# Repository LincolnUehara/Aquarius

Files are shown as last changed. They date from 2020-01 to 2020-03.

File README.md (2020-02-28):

# Project Aquarius



<p align="center">
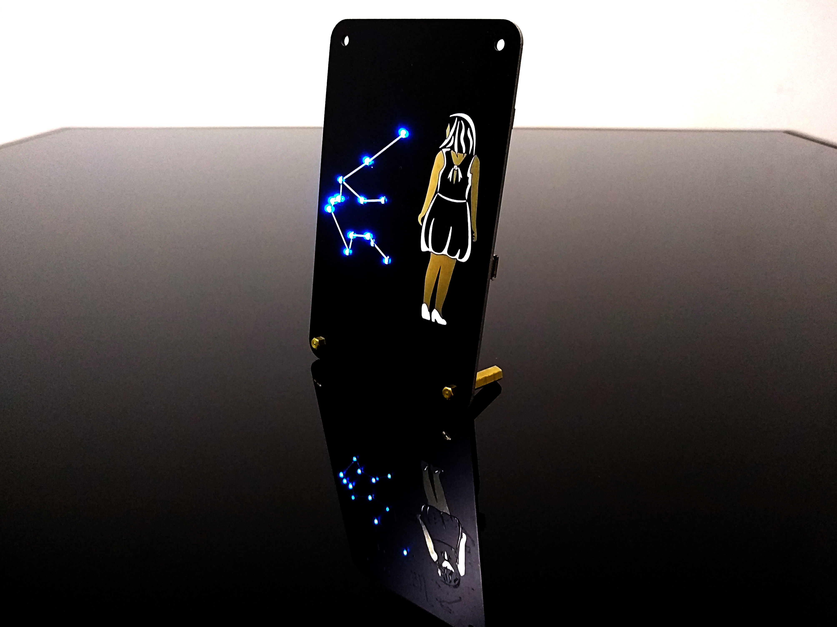
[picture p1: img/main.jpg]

</p>

I was looking for a hardware project to do, and in my research I found about artistical PCBs like [Badgelife](https://www.vice.com/en_us/article/vbne9a/a-history-of-badgelife-def-cons-unlikely-obsession-with-artistic-circuit-boards) and [SAOS](https://hackaday.com/2019/03/20/introducing-the-shitty-add-on-v1-69bis-standard/). Adding to that, since ever I am inspired by a photo that I took from a friend of mine. It looks like she is worry-free, weightless and at peace with herself, but still looking for something, and believing that astral energy wield upon her path.

<p align="center">
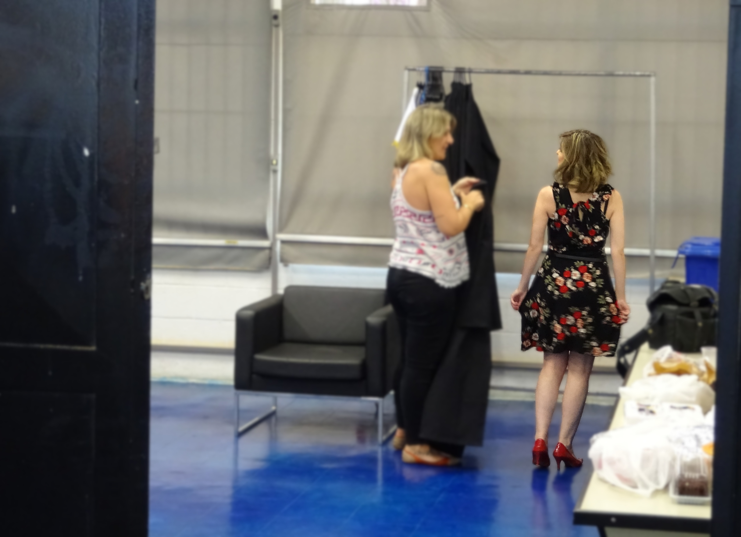
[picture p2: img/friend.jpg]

</p>

Thus, I've decided to make this project happen.

<p align="center">
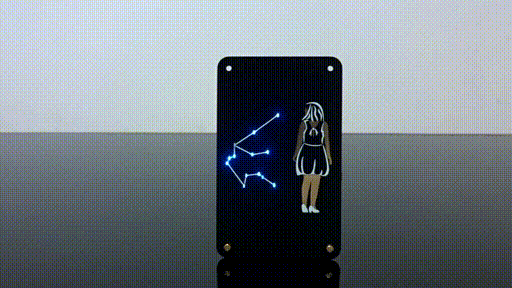
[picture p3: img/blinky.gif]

</p>

There is a _artistical_ promotional video for this project, you can check [here](https://youtu.be/2W8A3zgU_Mk).

### How it works?

Just turn on and the stars will shine! :star2:

* The power supply is from batteries or USB cable accordingly to switch select (where "Choose supply between USB or batteries" is written).

* There is a reset button to just do what it means to, and FTDI pads near to write the firmware into microcontroller.

* There are two trimpot to adjust the intensity and "frequency" of the stars. The stars blink in the way to avoid the predictability, and the control of "frequency" here means to set the average frequency, since each star does not blink every period in the same way.

* There is a USB connection but only for supplying for now. It is not implemented yet any kind of communication with the microcontroller via USB.

<p align="center">
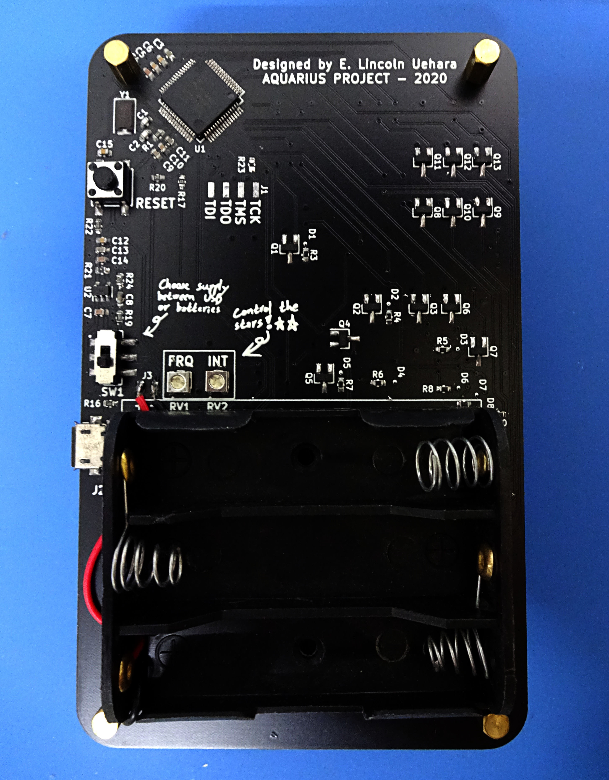
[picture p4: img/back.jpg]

</p>

### Links

* [hackster.io - PCB Portrait "Aquarius"](https://www.hackster.io/lin_hara/pcb-portrait-aquarius-eca035)
* [Kitspace - Aquarius](https://kitspace.org/boards/github.com/lincolnuehara/aquarius/)

### Author

Lincoln Uehara

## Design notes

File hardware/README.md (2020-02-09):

### Setting up Kicad environment

The version used is `5.1.5`.

1. On Symbol Editor:
* Go to _Preferences_ -> _Manage Symbol Libraries..._;
* On _Project Specific Libraries_ tab, add `aquarius.lib` and `ZX62-B-5PA(33).lib`.

2. On Footprint Editor:
* Go to _Preferences_ -> _Manage Footprint Libraries..._;
* On _Project Specific Libraries_ tab add `aquarius.pretty`, `TPS79733DCKT.mod`, `JS202011SCQN.mod` and `PVG3A205C01R00.mod`.

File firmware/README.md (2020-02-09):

### Setting up Eclipse IDE environment

* Go to _Project_ -> _Properties_;
* Go to _C/C++ Build_ -> _Environment_ -> _Variables_
* Just set the _PATH_ variable pointing to the ARM GCC compiler. For example: `${HOME}/opt/${GCC_VERSION}/bin:...`

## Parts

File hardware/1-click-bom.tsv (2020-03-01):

References | Qty | Description | Manufacturer | MPN | Digikey | Mouser | RS | Newark | Farnell
C1, C2 | 2 | C 10pF Unpolarized capacitor 0603 1608Metric | KEMET | C0603C100K4GACTU | C0603C100K4GACTU-ND | 80C0603C100K4GACTU |  |  | 2941182
C3 | 1 | C 2.2uF Unpolarized capacitor 0603 1608Metric | Taiyo Yuden | LMK107BJ225KK-T | 587-6290-6-ND | 963LMK107BJ225KKT
C4, C7, C14 | 3 | C 1.0uF Unpolarized capacitor 0603 1608Metric | TDK | CGA3E1X8L1C105K080AC | 445-175260-1-ND | 810CGA3E1X8L105K080
C6, C5, C10, C12, C15 | 5 | C 0.1uF Unpolarized capacitor 0603 1608Metric | KEMET | C0603X104K5RAC3316 | 399-C0603X104K5RAC3316CT-ND | 80C0603X104K5R3316 | 1882158
C8, C9, C11, C13 | 4 | C 0.01uF Unpolarized capacitor 0603 1608Metric | KEMET | C0603C103K4HACTU |  | 80C0603C103K4HACTU
D1, D2, D3, D4, D5, D11, D12, D13, D6, D7, D8, D9, D10 | 13 | LED Blue 0603 1608Metric | Dialight | 599-0091-007F | 350-4352-1-ND | 6455990091007F
J2 | 1 | USB Connectors MICRO B | Hirose | ZX62-B-5PA(33) | H125270DKR-ND | 798ZX62B5PA33 | 1362267 |  | 2554978
Q1, Q2, Q3, Q4, Q5, Q11, Q12, Q13, Q6, Q7, Q8, Q9, Q10 | 13 | Bipolar Transistors - Pre-Biased NPN SOT-23 | Rohm | DTC114ECAHZGT116 | DTC114ECAHZGT116DKR-ND | 755DTC114ECAHZGT116 |  |  | 2764559
R1, R20, R19, R16, R17 | 5 | R 0 Resistor 0603 1608Metric | Vishay | CRCW06030000Z0EBC | 541-4013-6-ND | 71CRCW06030000Z0EBC
R3, R4, R5, R6, R7, R13, R14, R15, R8, R9, R10, R11, R12 | 13 | R R100 Resistor 0603 1608Metric | KOA Speer | RN73R1JTTD1000F50 | 2019-RN73R1JTTD1000F50TR-ND | 660RN73R1JTD1000F50
R21 | 1 | R 51k Resistor 0603 1608Metric | Rohm | KTR03EZPF5102 | RHM51KAYCT-ND | 755KTR03EZPF5102 |  |  | 2919261
R22 | 1 | R 10k Resistor 0603 1608Metric | Vishay | CRCW060310K0FKEAC | 541-5136-6-ND | 71CRCW060310K0FKEAC
R23 | 1 | R 100k Resistor 0603 1608Metric | Panasonic | ERJ-PA3F1003V | P100KBYDKR-ND | 667ERJPA3F1003V | 8626708 |  | 2335832
R24 | 1 | R 30k Resistor 0603 1608Metric | Vishay | RCS060330K0FKEA | 541-10453-1-ND | 71RCS060330K0FKEA |  |  | 3235100
RV1, RV2 | 2 | SMD Trimmer Resistors 10Kohms | Bourns | PVG3A103C01R00 | 490-2644-2-ND | 81PVG3A103C01R00 | 1814466 |  | 2709480
SW1 | 1 | Slide Switches Slide Switches DPDT | C&K Components | JS202011SCQN | 401-2002-1-ND | 611JS202011SCQN | 1546137 |  | 2320019
SW2 | 1 | Tactile Switch SPST GEN PURPOSE | Omron | B3S-1000 | SW415-ND | 653B3S1000 | 183701 |  | 177807
U1 | 1 | MCU ARM Microcontrollers - Tiva C Series | Texas Instruments | TM4C123GH6PMI | 296-35848-ND | 595TM4C123GH6PMI |  |  | 3008366
U2 | 1 | LDO Voltage Regulators Cap-Free NMOS 400mA | Texas Instruments | TPS73633DBVR | 296-27064-6-ND | 595TPS73633DBVR |  |  | 3007880
Y1 | 1 | Crystal 16MHz SMD | Abracon | ABM3-16.000MHZ-B2-T | 535-9103-1-ND | 815ABM316B2T |  |  | 1611806

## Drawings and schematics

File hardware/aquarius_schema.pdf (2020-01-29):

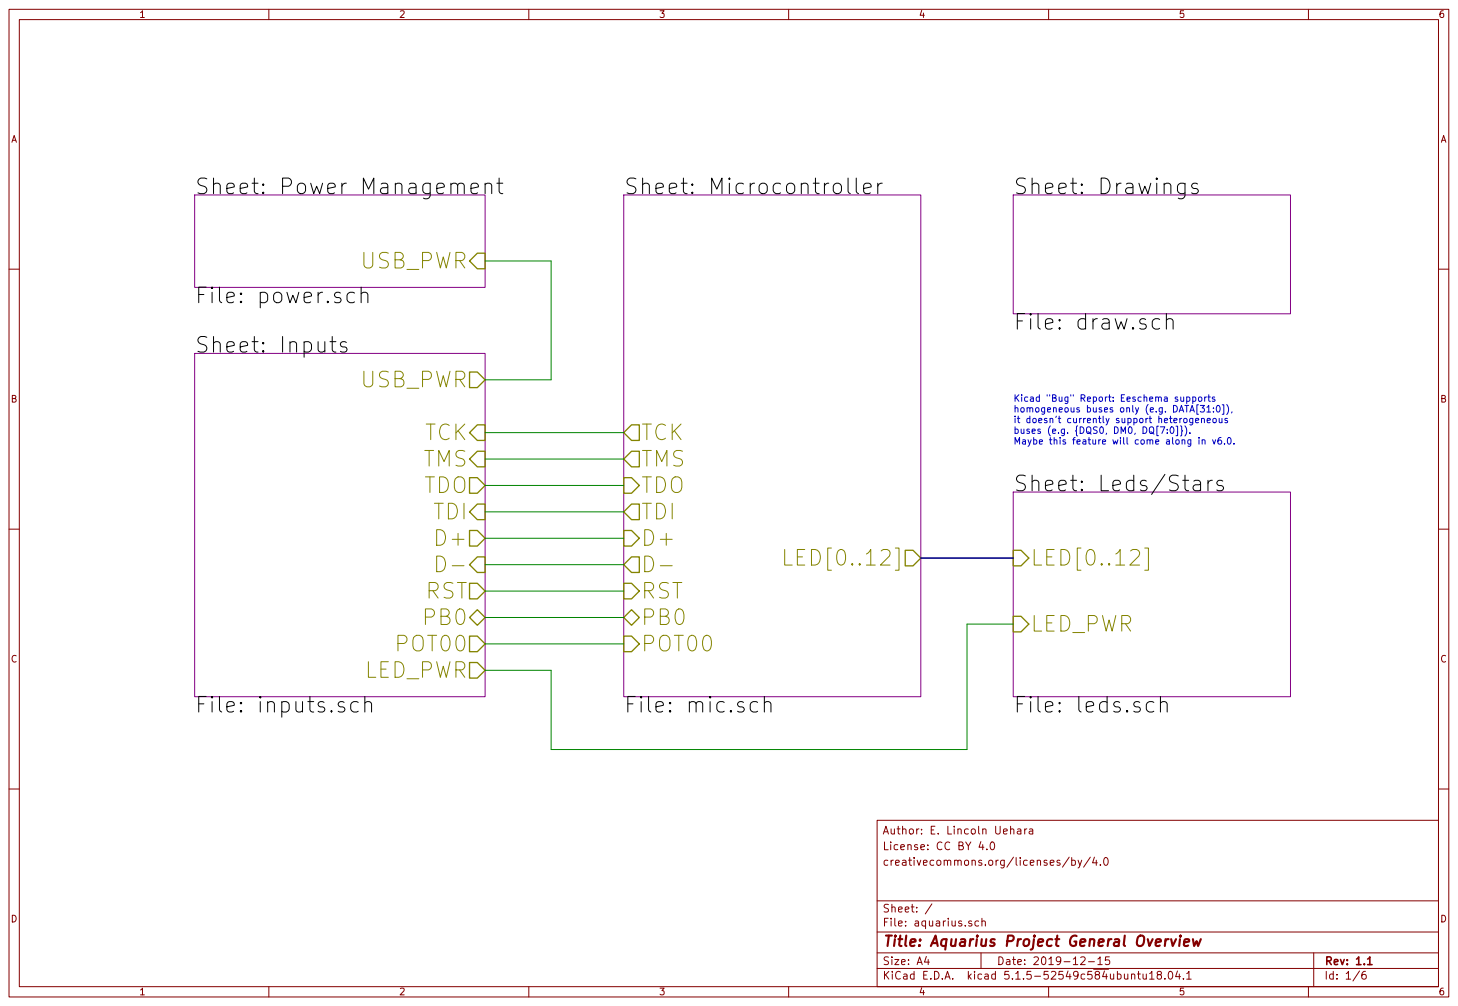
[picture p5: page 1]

Kicad "Bug" Report: Eeschema supports
homogeneous buses only (e.g. DATA[31:0]),
it doesnt currently support heterogeneous
buses (e.g. {DQS0, DM0, DQ[7:0]}).
Maybe this feature will come along in v6.0.

License: CC BY 4.0 Author: E. Lincoln Uehara Sheet: Leds/Stars

File: aquarius.sch Sheet: / creativecommons.org/licenses/by/4.0

Id: 1/6 Title: Aquarius Project General Overview

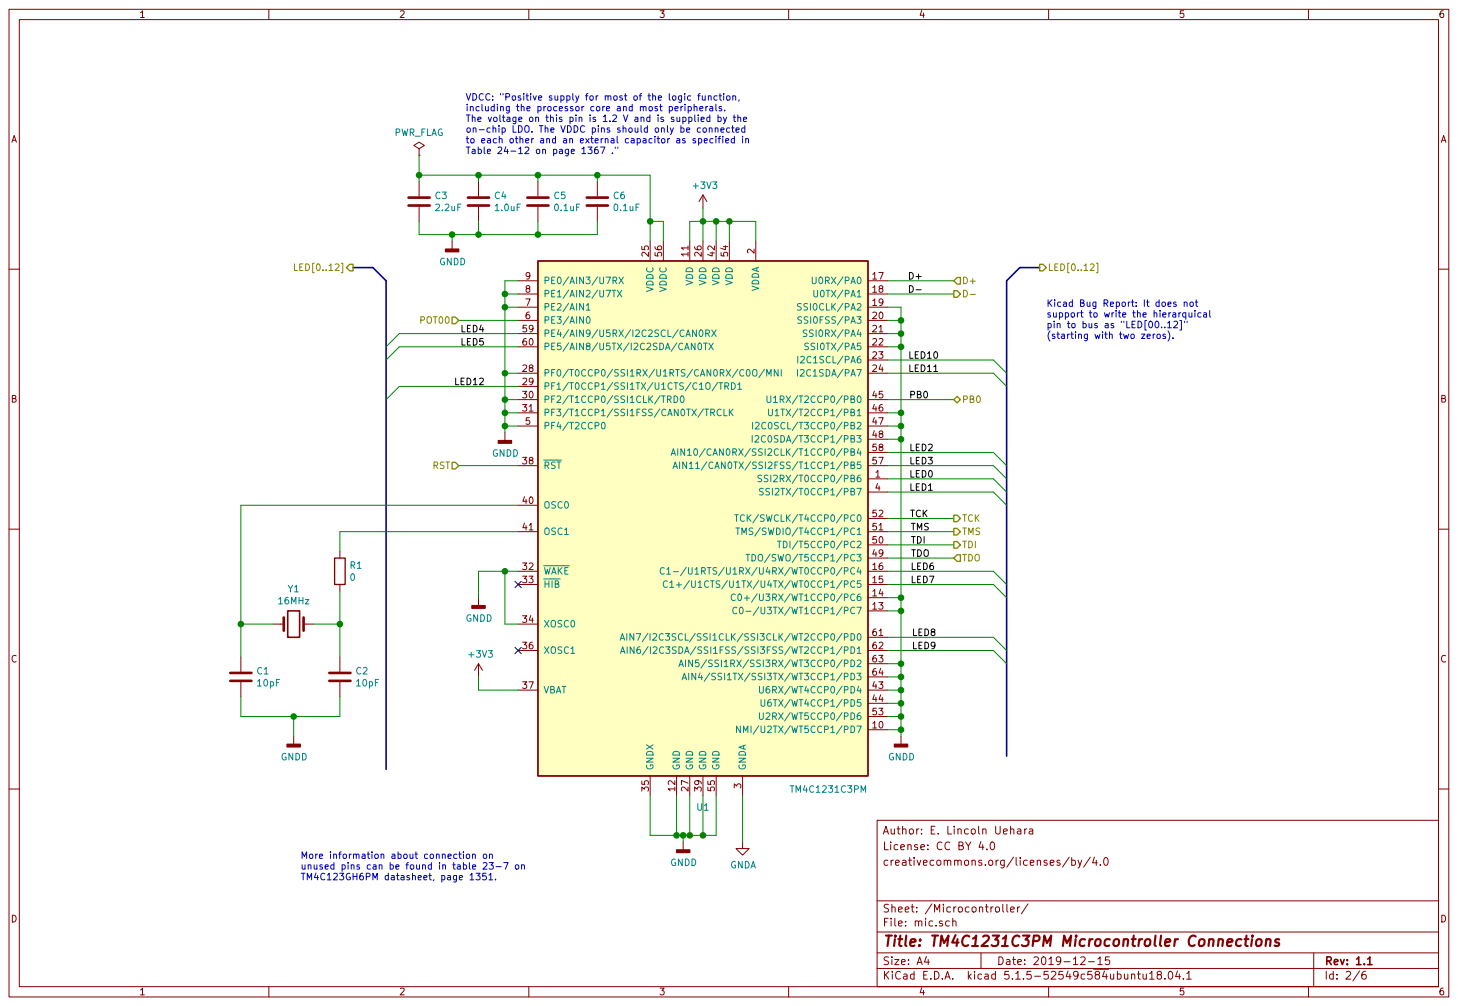
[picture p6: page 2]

VDCC: "Positive supply for most of the logic function,
including the processor core and most peripherals.
The voltage on this pin is 1.2 V and is supplied by the
on-chip LDO. The VDDC pins should only be connected
to each other and an external capacitor as specified in
Table 24-12 on page 1367 ."
2.2uF GNDD

3 SSI2TX/T0CCP1/PB7 4 PF4/T2CCP0 5 PE3/AIN0 6 PE2/AIN1 7 PE1/AIN2/U7TX 8 PE0/AIN3/U7RX 9 NMI/U2TX/WT5CCP1/PD7 10 SSI0FSS/PA3 20 PF2/T1CCP0/SSI1CLK/TRD0 30 OSC0 40 TDI/T5CCP0/PC2 50 PE5/AIN8/U5TX/I2C2SDA/CAN0TX 60 VDD 11 SSI0RX/PA4 21 PF3/T1CCP1/SSI1FSS/CAN0TX/TRCLK 31 OSC1 41 TMS/SWDIO/T4CCP1/PC1 51 AIN7/I2C3SCL/SSI1CLK/SSI3CLK/WT2CCP0/PD0 61 GND 12 SSI0TX/PA5 22 WAKE 32 VDD 42 TCK/SWCLK/T4CCP0/PC0 52 AIN6/I2C3SDA/SSI1FSS/SSI3FSS/WT2CCP1/PD1 62 C0-/U3TX/WT1CCP1/PC7 13

LED0 PB0 D- More information about connection on

Kicad Bug Report: It does not
support to write the hierarquical
pin to bus as "LED[00..12]"
(starting with two zeros).

License: CC BY 4.0 Author: E. Lincoln Uehara

File: mic.sch Sheet: /Microcontroller/ creativecommons.org/licenses/by/4.0

unused pins can be found in table 23-7 on
TM4C123GH6PM datasheet, page 1351.

Id: 2/6 Title: TM4C1231C3PM Microcontroller Connections

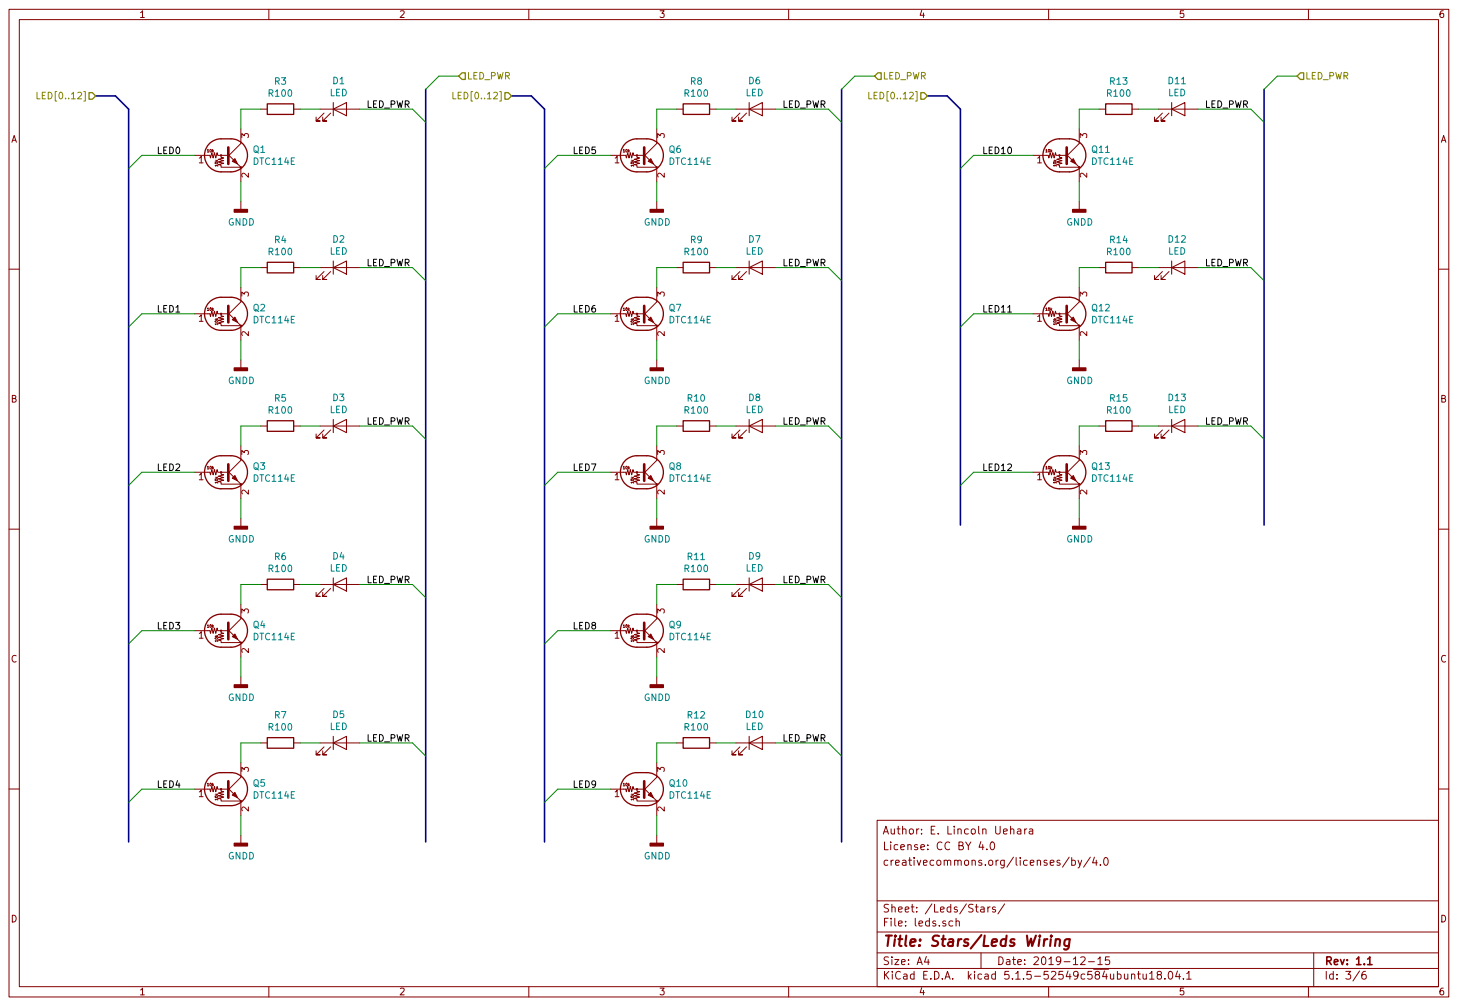
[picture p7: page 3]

License: CC BY 4.0 Author: E. Lincoln Uehara

File: leds.sch Sheet: /Leds/Stars/ creativecommons.org/licenses/by/4.0

Id: 3/6 Title: Stars/Leds Wiring

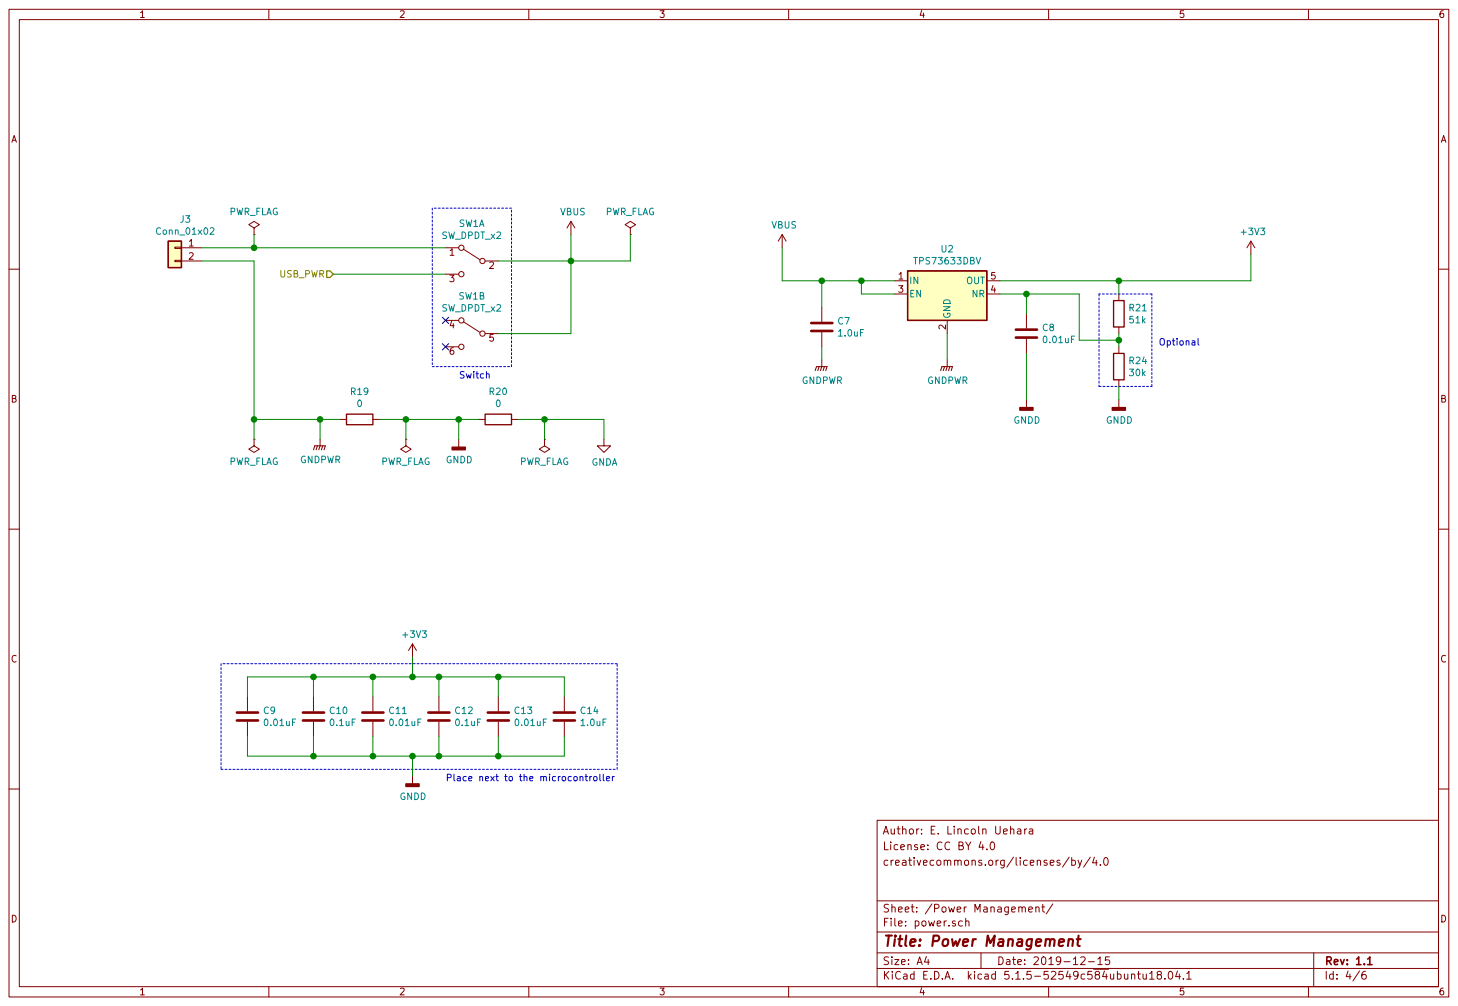
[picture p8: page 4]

2 EN 3 NR 4 OUT 5 U2 TPS73633DBV GNDPWR GNDD GNDPWR

License: CC BY 4.0 Author: E. Lincoln Uehara GNDD

creativecommons.org/licenses/by/4.0

Sheet: /Power Management/
File: power.sch
Id: 4/6 Title: Power Management

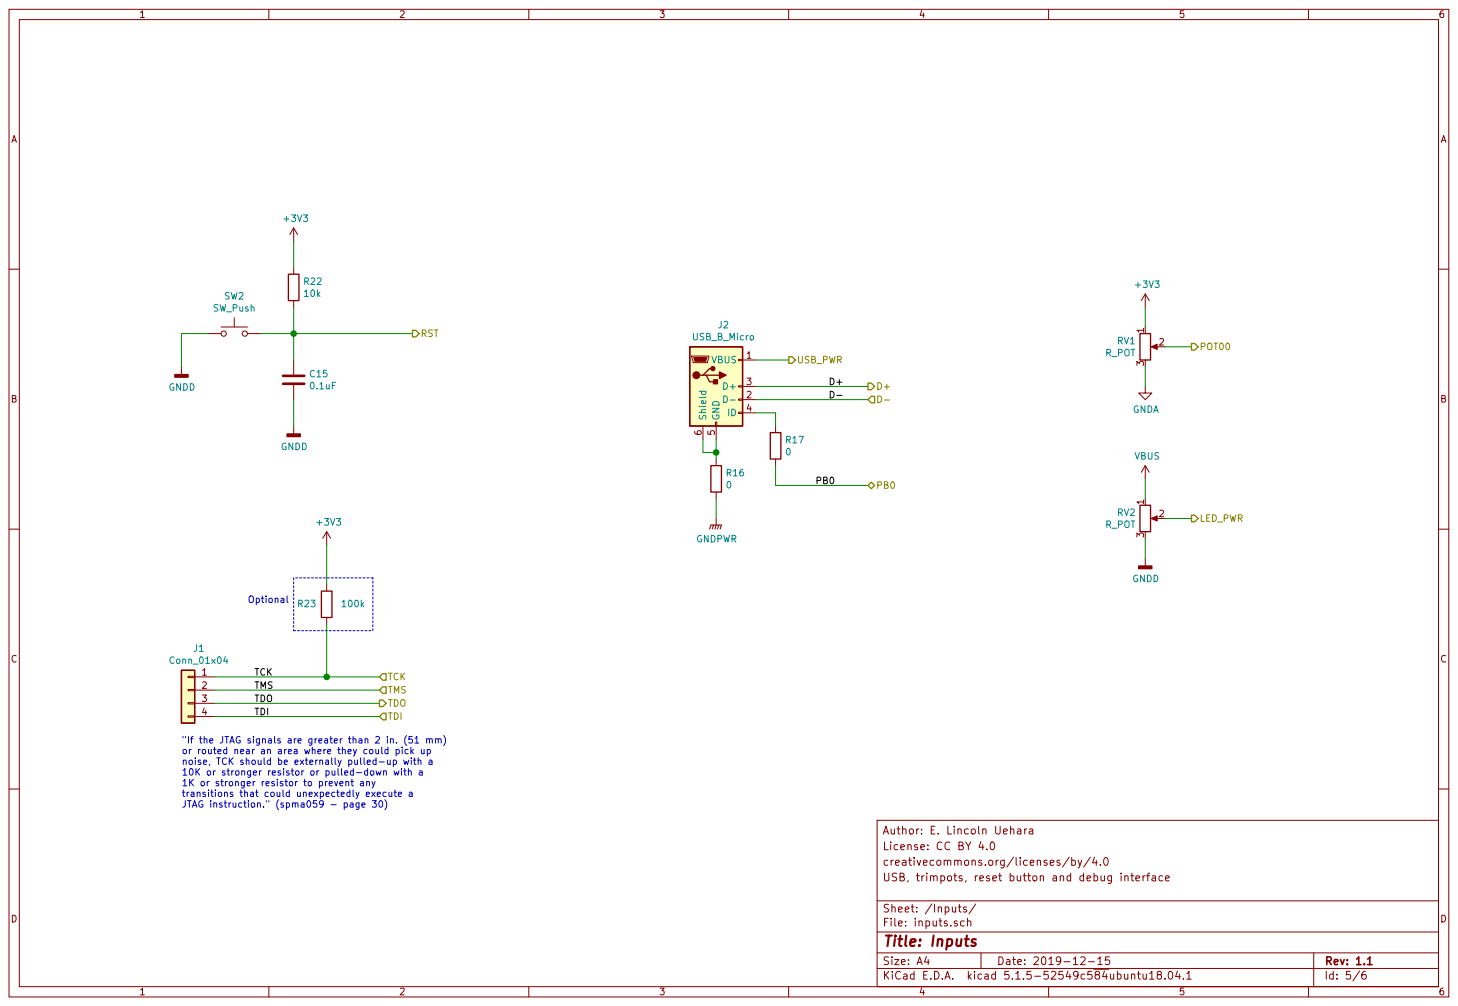
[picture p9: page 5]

"If the JTAG signals are greater than 2 in. (51 mm)
or routed near an area where they could pick up
noise, TCK should be externally pulled-up with a
10K or stronger resistor or pulled-down with a
1K or stronger resistor to prevent any
transitions that could unexpectedly execute a
JTAG instruction." (spma059 - page 30)

License: CC BY 4.0 Author: E. Lincoln Uehara

creativecommons.org/licenses/by/4.0
USB, trimpots, reset button and debug interface

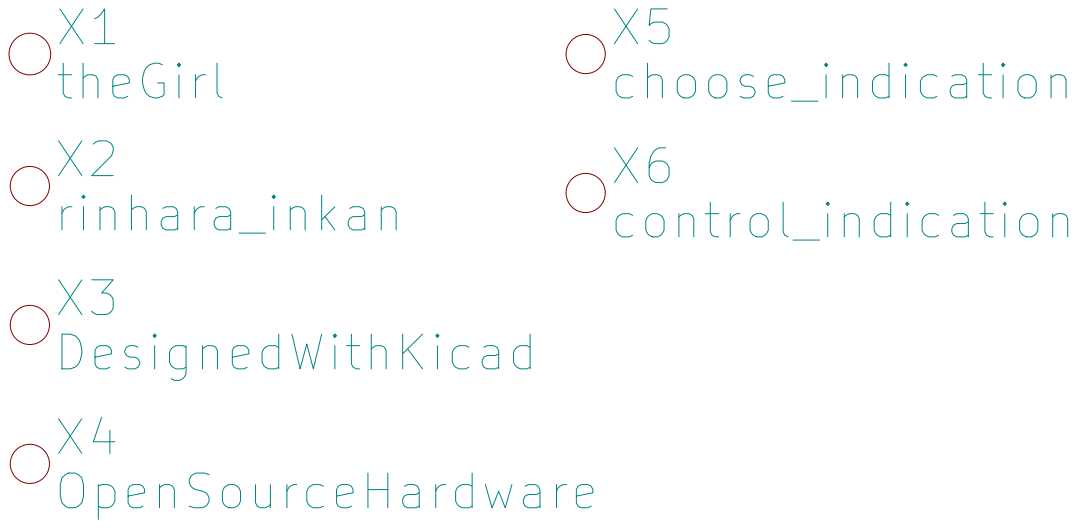
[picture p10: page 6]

creativecommons.org/licenses/by/4.0

File: draw.sch Sheet: /Drawings/
Id: 6/6 Title: PCB Drawings

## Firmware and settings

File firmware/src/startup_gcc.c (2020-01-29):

//*****************************************************************************
//
// startup_gcc.c - Startup code for use with GNU tools.
//
// Copyright (c) 2012-2016 Texas Instruments Incorporated.  All rights reserved.
// Software License Agreement
//
// Texas Instruments (TI) is supplying this software for use solely and
// exclusively on TI's microcontroller products. The software is owned by
// TI and/or its suppliers, and is protected under applicable copyright
// laws. You may not combine this software with "viral" open-source
// software in order to form a larger program.
//
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
// This is part of revision 2.1.3.156 of the EK-TM4C123GXL Firmware Package.
//
//*****************************************************************************

#include <stdint.h>
#include "inc/hw_nvic.h"
#include "inc/hw_types.h"

//*****************************************************************************
//
// Forward declaration of the default fault handlers.
//
//*****************************************************************************
void ResetISR(void);
static void NmiSR(void);
static void FaultISR(void);
static void IntDefaultHandler(void);

//*****************************************************************************
//
// External declarations for the interrupt handlers used by the application.
//
//*****************************************************************************
extern void starsBlink(void);

//*****************************************************************************
//
// The entry point for the application.
//
//*****************************************************************************
extern int main(void);

//*****************************************************************************
//
// Reserve space for the system stack.
//
//*****************************************************************************
static uint32_t pui32Stack[1024];

//*****************************************************************************
//
// The vector table.  Note that the proper constructs must be placed on this to
// ensure that it ends up at physical address 0x0000.0000.
//
//*****************************************************************************
__attribute__ ((section(".isr_vector")))
void (* const g_pfnVectors[])(void) =
{
    (void (*)(void))((uint32_t)pui32Stack + sizeof(pui32Stack)),
                                            // The initial stack pointer
    ResetISR,                               // The reset handler
    NmiSR,                                  // The NMI handler
    FaultISR,                               // The hard fault handler
    IntDefaultHandler,                      // The MPU fault handler
    IntDefaultHandler,                      // The bus fault handler
    IntDefaultHandler,                      // The usage fault handler
    0,                                      // Reserved
    0,                                      // Reserved
    0,                                      // Reserved
    0,                                      // Reserved
    IntDefaultHandler,                      // SVCall handler
    IntDefaultHandler,                      // Debug monitor handler
    0,                                      // Reserved
    IntDefaultHandler,                      // The PendSV handler
	IntDefaultHandler,                      // The SysTick handler
    IntDefaultHandler,                      // GPIO Port A
    IntDefaultHandler,                      // GPIO Port B
    IntDefaultHandler,                      // GPIO Port C
    IntDefaultHandler,                      // GPIO Port D
    IntDefaultHandler,                      // GPIO Port E
        IntDefaultHandler,// UART0 Rx and Tx
	IntDefaultHandler,                      // UART1 Rx and Tx
    IntDefaultHandler,                      // SSI0 Rx and Tx
    IntDefaultHandler,                      // I2C0 Master and Slave
    IntDefaultHandler,                      // PWM Fault
    IntDefaultHandler,                      // PWM Generator 0
    IntDefaultHandler,                      // PWM Generator 1
    IntDefaultHandler,                      // PWM Generator 2
    IntDefaultHandler,                      // Quadrature Encoder 0
    IntDefaultHandler,                      // ADC Sequence 0
    IntDefaultHandler,                      // ADC Sequence 1
    IntDefaultHandler,                      // ADC Sequence 2
    IntDefaultHandler,                      // ADC Sequence 3
    IntDefaultHandler,                      // Watchdog timer
        starsBlink,// Timer 0 subtimer A
    IntDefaultHandler,                      // Timer 0 subtimer B
    IntDefaultHandler,                      // Timer 1 subtimer A
    IntDefaultHandler,                      // Timer 1 subtimer B
    IntDefaultHandler,                      // Timer 2 subtimer A
    IntDefaultHandler,                      // Timer 2 subtimer B
    IntDefaultHandler,                      // Analog Comparator 0
    IntDefaultHandler,                      // Analog Comparator 1
    IntDefaultHandler,                      // Analog Comparator 2
    IntDefaultHandler,                      // System Control (PLL, OSC, BO)
    IntDefaultHandler,                      // FLASH Control
    IntDefaultHandler,                      // GPIO Port F
    IntDefaultHandler,                      // GPIO Port G
    IntDefaultHandler,                      // GPIO Port H
    IntDefaultHandler,                      // UART2 Rx and Tx
    IntDefaultHandler,                      // SSI1 Rx and Tx
	IntDefaultHandler,                      // Timer 3 subtimer A
    IntDefaultHandler,                      // Timer 3 subtimer B
    IntDefaultHandler,                      // I2C1 Master and Slave
    IntDefaultHandler,                      // Quadrature Encoder 1
    IntDefaultHandler,                      // CAN0
    IntDefaultHandler,                      // CAN1
    0,                                      // Reserved
    0,                                      // Reserved
    IntDefaultHandler,                      // Hibernate
    IntDefaultHandler,                      // USB0
    IntDefaultHandler,                      // PWM Generator 3
	IntDefaultHandler,                      // uDMA Software Transfer
        IntDefaultHandler,// uDMA Error
    IntDefaultHandler,                      // ADC1 Sequence 0
    IntDefaultHandler,                      // ADC1 Sequence 1
    IntDefaultHandler,                      // ADC1 Sequence 2
    IntDefaultHandler,                      // ADC1 Sequence 3
    0,                                      // Reserved
    0,                                      // Reserved
    IntDefaultHandler,                      // GPIO Port J
    IntDefaultHandler,                      // GPIO Port K
    IntDefaultHandler,                      // GPIO Port L
    IntDefaultHandler,                      // SSI2 Rx and Tx
    IntDefaultHandler,                      // SSI3 Rx and Tx
    IntDefaultHandler,                      // UART3 Rx and Tx
    IntDefaultHandler,                      // UART4 Rx and Tx
    IntDefaultHandler,                      // UART5 Rx and Tx
    IntDefaultHandler,                      // UART6 Rx and Tx
    IntDefaultHandler,                      // UART7 Rx and Tx
    0,                                      // Reserved
    0,                                      // Reserved
    0,                                      // Reserved
    0,                                      // Reserved
    IntDefaultHandler,                      // I2C2 Master and Slave
    IntDefaultHandler,                      // I2C3 Master and Slave
    IntDefaultHandler,                      // Timer 4 subtimer A
    IntDefaultHandler,                      // Timer 4 subtimer B
    0,                                      // Reserved
    0,                                      // Reserved
    0,                                      // Reserved
    0,                                      // Reserved
    0,                                      // Reserved
    0,                                      // Reserved
    0,                                      // Reserved
    0,                                      // Reserved
    0,                                      // Reserved
    0,                                      // Reserved
    0,                                      // Reserved
    0,                                      // Reserved
    0,                                      // Reserved
    0,                                      // Reserved
    0,                                      // Reserved
    0,                                      // Reserved
    0,                                      // Reserved
    0,                                      // Reserved
    0,                                      // Reserved
    0,                                      // Reserved
    IntDefaultHandler,                      // Timer 5 subtimer A
    IntDefaultHandler,                      // Timer 5 subtimer B
    IntDefaultHandler,                      // Wide Timer 0 subtimer A
    IntDefaultHandler,                      // Wide Timer 0 subtimer B
    IntDefaultHandler,                      // Wide Timer 1 subtimer A
    IntDefaultHandler,                      // Wide Timer 1 subtimer B
    IntDefaultHandler,                      // Wide Timer 2 subtimer A
    IntDefaultHandler,                      // Wide Timer 2 subtimer B
    IntDefaultHandler,                      // Wide Timer 3 subtimer A
    IntDefaultHandler,                      // Wide Timer 3 subtimer B
    IntDefaultHandler,                      // Wide Timer 4 subtimer A
    IntDefaultHandler,                      // Wide Timer 4 subtimer B
    IntDefaultHandler,                      // Wide Timer 5 subtimer A
    IntDefaultHandler,                      // Wide Timer 5 subtimer B
    IntDefaultHandler,                      // FPU
    0,                                      // Reserved
    0,                                      // Reserved
    IntDefaultHandler,                      // I2C4 Master and Slave
    IntDefaultHandler,                      // I2C5 Master and Slave
    IntDefaultHandler,                      // GPIO Port M
    IntDefaultHandler,                      // GPIO Port N
    IntDefaultHandler,                      // Quadrature Encoder 2
    0,                                      // Reserved
    0,                                      // Reserved
    IntDefaultHandler,                      // GPIO Port P (Summary or P0)
    IntDefaultHandler,                      // GPIO Port P1
    IntDefaultHandler,                      // GPIO Port P2
    IntDefaultHandler,                      // GPIO Port P3
    IntDefaultHandler,                      // GPIO Port P4
    IntDefaultHandler,                      // GPIO Port P5
    IntDefaultHandler,                      // GPIO Port P6
    IntDefaultHandler,                      // GPIO Port P7
    IntDefaultHandler,                      // GPIO Port Q (Summary or Q0)
    IntDefaultHandler,                      // GPIO Port Q1
    IntDefaultHandler,                      // GPIO Port Q2
    IntDefaultHandler,                      // GPIO Port Q3
    IntDefaultHandler,                      // GPIO Port Q4
    IntDefaultHandler,                      // GPIO Port Q5
    IntDefaultHandler,                      // GPIO Port Q6
    IntDefaultHandler,                      // GPIO Port Q7
    IntDefaultHandler,                      // GPIO Port R
    IntDefaultHandler,                      // GPIO Port S
    IntDefaultHandler,                      // PWM 1 Generator 0
    IntDefaultHandler,                      // PWM 1 Generator 1
    IntDefaultHandler,                      // PWM 1 Generator 2
    IntDefaultHandler,                      // PWM 1 Generator 3
    IntDefaultHandler                       // PWM 1 Fault
};

//*****************************************************************************
//
// The following are constructs created by the linker, indicating where the
// the "data" and "bss" segments reside in memory.  The initializers for the
// for the "data" segment resides immediately following the "text" segment.
//
//*****************************************************************************
extern uint32_t _etext;
extern uint32_t _data;
extern uint32_t _edata;
extern uint32_t _bss;
extern uint32_t _ebss;

//*****************************************************************************
//
// This is the code that gets called when the processor first starts execution
// following a reset event.  Only the absolutely necessary set is performed,
// after which the application supplied entry() routine is called.  Any fancy
// actions (such as making decisions based on the reset cause register, and
// resetting the bits in that register) are left solely in the hands of the
// application.
//
//*****************************************************************************
void
ResetISR(void)
{
    uint32_t *pui32Src, *pui32Dest;

    //
    // Copy the data segment initializers from flash to SRAM.
    //
    pui32Src = &_etext;
    for(pui32Dest = &_data; pui32Dest < &_edata; )
    {
        *pui32Dest++ = *pui32Src++;
    }

    //
    // Zero fill the bss segment.
    //
    __asm("    ldr     r0, =_bss\n"
          "    ldr     r1, =_ebss\n"
          "    mov     r2, #0\n"
          "    .thumb_func\n"
          "zero_loop:\n"
          "        cmp     r0, r1\n"
          "        it      lt\n"
          "        strlt   r2, [r0], #4\n"
          "        blt     zero_loop");

    //
    // Enable the floating-point unit.  This must be done here to handle the
    // case where main() uses floating-point and the function prologue saves
    // floating-point registers (which will fault if floating-point is not
    // enabled).  Any configuration of the floating-point unit using DriverLib
    // APIs must be done here prior to the floating-point unit being enabled.
    //
    // Note that this does not use DriverLib since it might not be included in
    // this project.
    //
    HWREG(NVIC_CPAC) = ((HWREG(NVIC_CPAC) &
                         ~(NVIC_CPAC_CP10_M | NVIC_CPAC_CP11_M)) |
                        NVIC_CPAC_CP10_FULL | NVIC_CPAC_CP11_FULL);

    //
    // Call the application's entry point.
    //
    main();
}

//*****************************************************************************
//
// This is the code that gets called when the processor receives a NMI.  This
// simply enters an infinite loop, preserving the system state for examination
// by a debugger.
//
//*****************************************************************************
static void
NmiSR(void)
{
    //
    // Enter an infinite loop.
    //
    while(1)
    {
    }
}

//*****************************************************************************
//
// This is the code that gets called when the processor receives a fault
// interrupt.  This simply enters an infinite loop, preserving the system state
// for examination by a debugger.
//
//*****************************************************************************
static void
FaultISR(void)
{
    //
    // Enter an infinite loop.
    //
    while(1)
    {
    }
}

//*****************************************************************************
//
// This is the code that gets called when the processor receives an unexpected
// interrupt.  This simply enters an infinite loop, preserving the system state
// for examination by a debugger.
//
//*****************************************************************************
static void
IntDefaultHandler(void)
{
    //
    // Go into an infinite loop.
    //
    while(1)
    {
    }
}

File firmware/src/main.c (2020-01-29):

/*
 * ANINHA PROJECT - main.c
 *
 * @author : Everton Lincoln Uehara
 * @date   : 2019-01-22
 * @brief  : [DESCRIPTION]
 *
 ******************************************************************************
 * BSD 2-Clause License
 *
 * Copyright (c) 2018, Everton Lincoln Uehara
 * All rights reserved.
 *
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
 * THIS SOFTWARE IS PROVIDED BY THE COPYRIGHT HOLDERS AND CONTRIBUTORS "AS IS"
 * AND ANY EXPRESS OR IMPLIED WARRANTIES, INCLUDING, BUT NOT LIMITED TO, THE
 * IMPLIED WARRANTIES OF MERCHANTABILITY AND FITNESS FOR A PARTICULAR PURPOSE ARE
 * DISCLAIMED. IN NO EVENT SHALL THE COPYRIGHT HOLDER OR CONTRIBUTORS BE LIABLE
 * FOR ANY DIRECT, INDIRECT, INCIDENTAL, SPECIAL, EXEMPLARY, OR CONSEQUENTIAL
 * DAMAGES (INCLUDING, BUT NOT LIMITED TO, PROCUREMENT OF SUBSTITUTE GOODS OR
 * SERVICES; LOSS OF USE, DATA, OR PROFITS; OR BUSINESS INTERRUPTION) HOWEVER
 * CAUSED AND ON ANY THEORY OF LIABILITY, WHETHER IN CONTRACT, STRICT LIABILITY,
 * OR TORT (INCLUDING NEGLIGENCE OR OTHERWISE) ARISING IN ANY WAY OUT OF THE USE
 * OF THIS SOFTWARE, EVEN IF ADVISED OF THE POSSIBILITY OF SUCH DAMAGE.
 *****************************************************************************
 */

#include <stdbool.h>
#include <stdint.h>
#include "../mcu/hw_clock.h"
#include "stars.h"
#include "inputs.h"

static uint32_t pot1Level = 0;
static uint8_t actualBright = 0;
static uint8_t lastBright = 0;
static uint32_t pot2Level = 0;
static uint8_t actualFreq = 0;
static uint8_t lastFreq = 0;
static bool firstRead = true;

int main(void) {

    /* First */
    clock_init();

    /*  */
    starsInit();
    inputsInit();

    while (1) {

        /* */
        inputsStartRead();

        pot1Level = inputsGetValue(INPUT_1);
        pot2Level = inputsGetValue(INPUT_2);

        /*  */
        if (pot1Level <= INLVL_1) {
            actualBright = BRLVL_1;
        } else if ((pot1Level > INLVL_1) && (pot1Level <= INHYS_1)) {
            if (firstRead == true) {
                actualBright = BRLVL_1;
            } else {
                actualBright = lastBright;
            }
        } else if ((pot1Level > INHYS_1) && (pot1Level <= INLVL_2)) {
            actualBright = BRLVL_2;
        } else if ((pot1Level > INLVL_2) && (pot1Level <= INHYS_2)) {
            if (firstRead == true) {
                actualBright = BRLVL_2;
            } else {
                actualBright = lastBright;
            }
        } else if ((pot1Level > INHYS_2) && (pot1Level <= INLVL_3)) {
            actualBright = BRLVL_3;
        } else if ((pot1Level > INLVL_3) && (pot1Level <= INHYS_3)) {
            if (firstRead == true) {
                actualBright = BRLVL_3;
            } else {
                actualBright = lastBright;
            }
        } else if ((pot1Level > INHYS_3) && (pot1Level <= INLVL_4)) {
            actualBright = BRLVL_4;
        }

        /*  */
        if (pot2Level <= INLVL_1) {
            actualFreq = FRLVL_1;
        } else if ((pot2Level > INLVL_1) && (pot2Level <= INHYS_1)) {
            if (firstRead == true) {
                actualFreq = FRLVL_1;
            } else {
                actualFreq = lastFreq;
            }
        } else if ((pot2Level > INHYS_1) && (pot2Level <= INLVL_2)) {
            actualFreq = FRLVL_2;
        } else if ((pot2Level > INLVL_2) && (pot2Level <= INHYS_2)) {
            if (firstRead == true) {
                actualFreq = FRLVL_2;
            } else {
                actualFreq = lastFreq;
            }
        } else if ((pot2Level > INHYS_2) && (pot2Level <= INLVL_3)) {
            actualFreq = FRLVL_3;
        } else if ((pot2Level > INLVL_3) && (pot2Level <= INHYS_3)) {
            if (firstRead == true) {
                actualFreq = FRLVL_3;
            } else {
                actualFreq = lastFreq;
            }
        } else if ((pot2Level > INHYS_3) && (pot2Level <= INLVL_4)) {
            actualFreq = FRLVL_4;
        }

        lastBright = actualBright;
        lastFreq = actualFreq;
        firstRead = false;
        starsSet(true, actualBright, actualFreq);
    }
}

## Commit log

2020-02-09 Adding more material
    [aquarius.kicad_pcb, aquarius.sch, draw.sch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]
2020-02-23 BOM and gerbers added
    [aquarius-BOM.ods]
2020-02-24 Updating gerbers
    [aquarius-B_Cu.gbr, aquarius-B_Mask.gbr, aquarius-B_Paste.gbr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]
2020-02-24 Adding csv file
    [aquarius-BOM.csv]
2020-02-25 Reorganizing BOM and correcting kitspace.yaml
    [aquarius-BOM.csv, aquarius-BOM.ods]
2020-02-25 Updating BOM and kitspace.yaml
    [1-click-bom.tsv, aquarius-BOM.csv]
2020-02-28 Updating gerbers and BOM
    [1-click-bom.tsv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]
2020-03-01 Updating BOM
    [1-click-bom.tsv]
